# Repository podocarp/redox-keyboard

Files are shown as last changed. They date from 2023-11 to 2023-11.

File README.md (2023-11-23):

## Changes

This is a fork of the original. Additions:
- Added v1 version that uses low profile Kailh choc hot swap sockets compatible
  with both v1 and v2 switches
- Added v1 version that uses Kailh MX hot swap sockets

<p align="center">
Redox logo
QMK
</p>

<h3 align="center">The Redox project repository</h3>

<div align="center">

[]()




</div>

---

The Redox project is an open-source, [QMK (Quantum Mechanical Keyboard Firmware)](https://github.com/qmk/qmk_firmware) powered, ergonomic split mechanical keyboard. This repository will be used to share information about the project and instruction on how to use and assemble the Redox keyboard.

<p align="center">
Redox
</p>

**Designer's bio**: [Mattia Dal Ben (aka u/TiaMaT102)](mailto:matthewdibi@gmail.com) obtained a master's degree in Electrical Engineering with a specialization in Computer Science at the University of Udine. Currently works as a Software Engineer in R&D department for a big IoT and Embedded Computers company. Mechanical keyboard enthusiast and maker, the Redox keyboard is the result of all of his passions.

## Rationale

The Redox is a keyboard project designed with ergonomics in mind. It uses Cherry MX style mechanical switches laid out in a 7x5 columnar stagger layout with components that can easily be sourced.

The design was heavily inspired by the [Ergodox keyboard](https://www.ergodox.io/), and its main goal is to reduce the size without sacrificing too many keys, hence the name **Re**duced Ergo**dox**.

As an Ergodox user I couldn't ignore the few flaws of the original design and in a moment of arrogance I tried to fix them, thus the Redox features:
- Easier to reach thumb cluster.
- Additional easy-to-reach rotated 1.25u thumb key.
- Reduced size.
- Reduced costs (the Redox uses Arduino Pro Micro instead of the Teensy 2.0).
- Either half can be plugged in to the PC since each half can act as the master.
- Either half can work as a standalone keyboard to be used as a macropad/gaming keyboard.
- RGB backlighting support.
- 3D-printer friendly case.
- Wireless [see section below](#wireless-implementations)
- [VIA](https://caniusevia.com/) compatible (thanks to [Harshit Goel](https://github.com/harshitgoel96))
- [ZMK firmware](https://zmk.dev/) compatible (thanks to [toddmok](https://github.com/toddmok))
- [KMK firmware](http://kmkfw.io/) compatible

## Related Projects

- [**Redox handwire**](https://www.thingiverse.com/thing:2704567): The first incarnation of the Redox keyboard. It consists of a 3D-printed case and a handwired matrix.
  - [Tilted Redox case](https://www.thingiverse.com/thing:2767216): tilted case for the Redox prototype by jschloer.
    - [Tilted redox case pro micro](https://www.printables.com/model/382413-tilted-redox-case-for-micro-and-usbc): Remix of the tilted case to support pro micro and usb c instead of TRRS. 

  - [couscous-kbd](https://gitlab.com/cschalkwijk/couscous-kbd): Redox-inspired parametric OpenSCAD keyboard design.
  - [Redox tenting kit](https://www.thingiverse.com/make:484843): modified base to support tenting, mini-USB for the interconnect, and a hole for microswitch for reset needed when uploading new firmware by [Lenbok](https://github.com/Lenbok).
  - [Iris-inspired Redox case](https://github.com/Lenbok/scad-redox-case): a case inspired both by the Redox rev1.0 and the Iris designed with OpenSCAD by [Lenbok](https://github.com/Lenbok).
  - [Redodactyl keyboard](https://www.reddit.com/r/MechanicalKeyboards/comments/9j5pw5/enter_the_redodactyl_first_build/): handwired 3D printed Dactyl-inspired Redox variant by u/darknao.
- [**Redox Manuform**](https://www.thingiverse.com/thing:3503380): full rework of the Redox case inspired by the Dactyl Manuform. Designed by [Fosk\_LL](https://www.thingiverse.com/Fosk_LL/about).
- [**Redox rev1.0**](https://github.com/mattdibi/redox-keyboard/tree/master/redox): the Redox rev 1.0 is the first commercially available version of the Redox keyboard.
	- Rev1.0 PCBs: available at [Falbatech's store](https://falba.tech/product/redox-pcb-electrical-boards-set-of-2/)
    - Firmware sources:
        - [QMK firmware for Redox](https://github.com/mattdibi/qmk_firmware/tree/master/keyboards/redox)
        - [KMK firmware for Redox](https://github.com/KMKfw/kmk_firmware/tree/master/boards/redox)
	- 3D-printable cases:
        - [3D printable case](https://www.thingiverse.com/thing:2886662), freely available.
        - [Redox keyboard case (high profile)](https://www.thingiverse.com/thing:3825752), by [Michele Ferri](https://www.thingiverse.com/sako83/about).
        - [Travel-friendly Redox Keyboard case](https://www.thingiverse.com/thing:3607303), by [Fosk\_LL](https://www.thingiverse.com/Fosk_LL/about).
        - [Redox Neodox case](https://github.com/Pastitas/Redox-neodox-Case), by [Pastitas](https://github.com/Pastitas)
        - [Redox big battery](https://github.com/marco-silvestri/redox-big-battery), by [Marco Silvestri](https://github.com/marco-silvestri).
	- Commercially available cases:
		- [Falbatech's bamboo cases with tilt kit](https://falba.tech/product/redox-standard-lift-bamboo-wood-case-with-oil-finish/)
		- [Falbatech's fullhand bamboo cases](https://falba.tech/product/redox-fullhand-bamboo-wood-case-with-oil-finish-ver-2/)
- [**Redox rev1.0W**](https://github.com/mattdibi/redox-keyboard/tree/master/redox-w): the Redox rev 1.0W is the wireless version of the Redox keyboard.
    - Rev1.0W PCBs: gerbers available in [this repo](https://github.com/mattdibi/redox-keyboard/tree/master/redox-w/rev1.0W).
    - Falbatech's Rev1.0W Hot-swap PCBs: available at [Falbatech's store](https://falba.tech/product/redox-wireless-pcb-electrical-boards-set-of-2/) (Incompatible with the 3D-printable cases down below)
    - Firmware sources:
        - [QMK firmware for Redox wireless](https://github.com/mattdibi/qmk_firmware/tree/master/keyboards/redox_w)
        - [Nordic MCUs firmware for Redox wireless](https://github.com/mattdibi/redox-w-firmware)
	- 3D-printable cases:
        - [3D printed case](https://github.com/mattdibi/redox-keyboard/tree/master/redox-w/case), freely available.
        - [Redox Neodox case](https://github.com/Pastitas/Redox-neodox-Case), by [Pastitas](https://github.com/Pastitas)
    - Commercially available cases (only compatible with the Falbatech's store PCBs):
        - [Falbatech's bamboo and aliminium cases](https://falba.tech/product/redox-wireless-standard-lift-bamboo-wood-case-with-oil-finish/)
		- [Falbatech's fullhand bamboo cases](https://falba.tech/product/redox-wireless-standard-lift-bamboo-wood-case-with-oil-finish-ver-1/)
- [**Redox rev2.0WHS**](https://github.com/mattdibi/redox-keyboard/tree/master/redox-w): the Redox rev 2.0WHS is the wireless hot-swappable version of the Redox keyboard.
    - Rev2.0WHS PCBs: gerber files available [here](https://github.com/mattdibi/redox-keyboard/tree/master/redox-w/rev2.0WHS/pcb)
    - Firmware sources:
        - [QMK firmware for Redox wireless](https://github.com/mattdibi/qmk_firmware/tree/master/keyboards/redox_w)
        - [Nordic MCUs firmware for Redox wireless](https://github.com/mattdibi/redox-w-firmware)
	- 3D-printable case:
        - [3D printed case](https://github.com/mattdibi/redox-keyboard/tree/master/redox-w/rev2.0WHS/case), freely available.

## Wireless Implementations

The Redox keyboard uses three different wireless implementations, differentiated by firmware:
 - *QMK based*: Leveraging the [Gazel protocol](https://developer.nordicsemi.com/nRF5_SDK/nRF51_SDK_v5.x.x/doc/5.2.0/html/a00140.html). It needs its own PCB and a receiver dongle (see [Redox Wireless](https://github.com/mattdibi/redox-keyboard/tree/docs/zmk_update/redox-w) for details) and needs three YJ-14015 MCUs + a Pro Micro compatible controller.
 - *ZMK based*: Leveraging the Bluetooth protocol. It is based on the [Redox wired PCB](https://github.com/mattdibi/redox-keyboard/tree/master/redox) and the [nice!nano](https://nicekeyboards.com/nice-nano/) controller.
 - *KMK based*: Adding [Bluetooth Split](http://kmkfw.io/docs/split_keyboards#bluetooth-split-aka-no-trrs-currently-in-testing) code to `boards/redox/main.py`. Combined with a [compatible](http://kmkfw.io/docs/Officially_Supported_Microcontrollers) wireless controller completes wireless configuration. Would advice adding [Bluetooth keycodes](http://kmkfw.io/docs/keycodes#bluetooth-keys) in keymap; `keyboard.keymap` element in `main.py`.

 The notable differences for the three implementations are as follows:
 - _Battery life_: QMK Redox Wireless uses two CR2032 coin cell batteries which last [approximately one year (YMMV)](https://github.com/mattdibi/redox-keyboard/tree/master/redox-w#battery-usage), while the nice!nano support LiPo rechargable batteries (you can choose the capacity you want but expect them to last for a [few weeks on a single charge](https://zmk.dev/power-profiler)).
 - _Flexibility_: The receiver dongle limits the flexibility of QMK Redox Wireless.
 - _Cost_: The 3x YJ-14015 + Pro Micro combo is cheaper than two wireless controllers required for ZMK and wireless KMK.
 - _Range_: Bluetooth implementations, of ZMK and KMK, should be more capable than what can be achieved with the QMK Redox Wireless (At this point in time, I lack the evidence to support these claims though).

## Physical Key Layout

<p align="center">
Redox layout
</p>

### Keycaps

| Size  | Qty | Notes |
|---|:---:|:---:|
| 1.5u  | 6 | |
| 1.25u |  10 | You can get away with 8 if you use two 1u keycaps for the 1.25u rotated keys |
| 1u |  54 | |

> :information_source: On [pimpmykeyboard.com](https://pimpmykeyboard.com/sa-1976-keyset-two-shot/) site you can find a SA 1976 keyset kit specifically made for the Redox keyboard: the "Ergo Redox kit (12 keys)".

## Affiliations

In partnership with Falbatech you can now use the code "**mattdibi05**" on Falbatech's store for a 5% OFF special discount.

## Donations

If you've read this far and found something useful, please consider donating to help me maintain and further develop this project.

<p align="center">
<a href="https://www.paypal.me/MattiaDalBen">Donate button</a>
</p>

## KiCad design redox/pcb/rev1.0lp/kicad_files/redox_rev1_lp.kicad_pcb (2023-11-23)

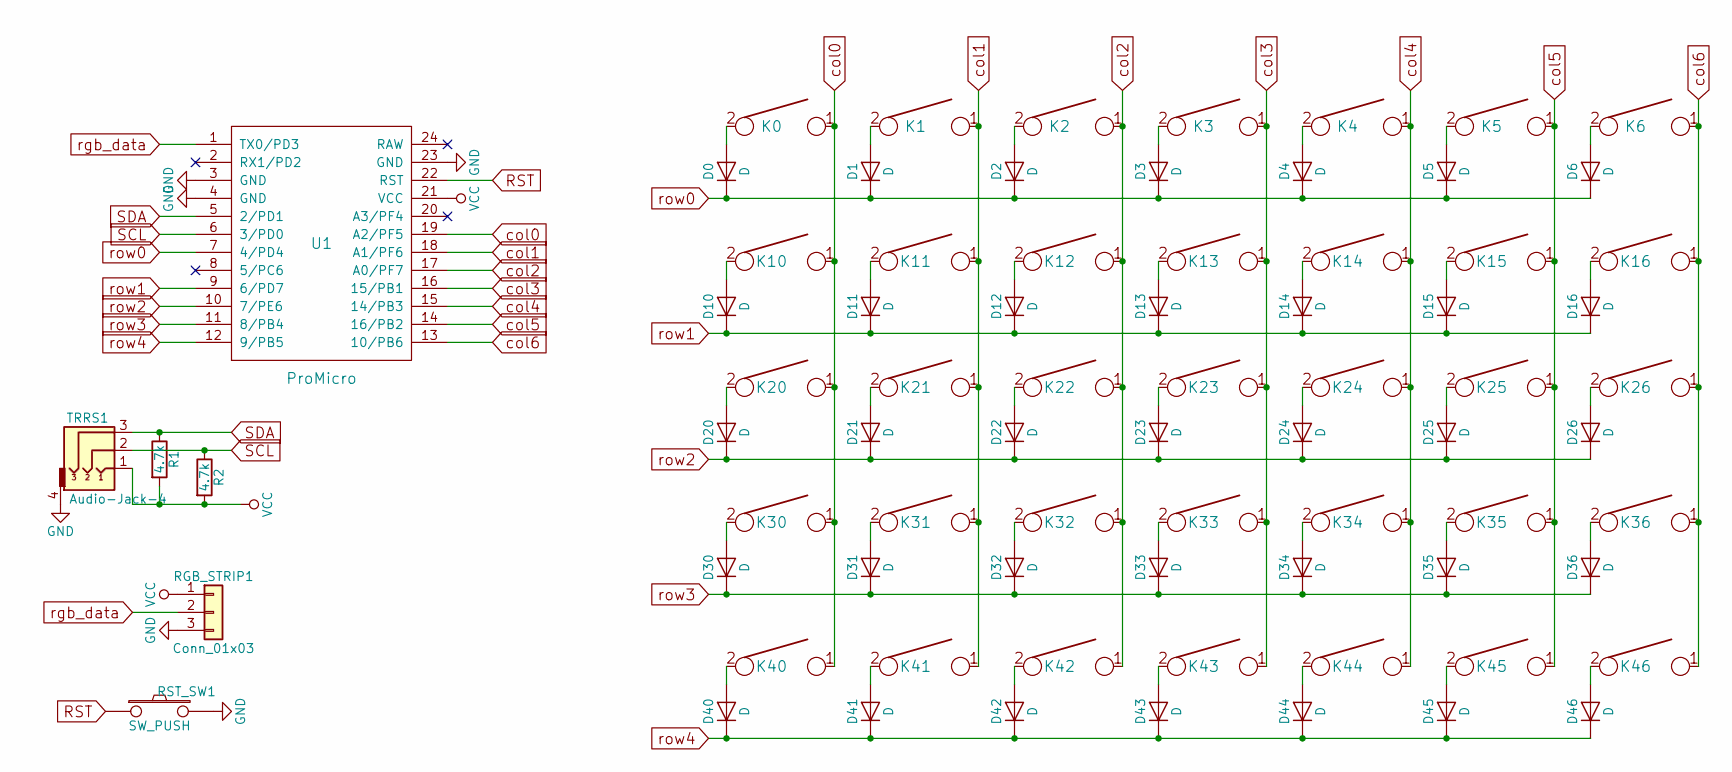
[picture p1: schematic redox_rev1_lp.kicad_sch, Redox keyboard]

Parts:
D0, D1, D2, D3, D4, D5, D6, D10, D11, D12, D13, D14, D15, D16, D20, D21, D22, D23, D24, D25, D26, D30, D31, D32, D33, D34, D35, D36, D40, D41, D42, D43, D44, D45, D46: D; Diode-dual
K0, K10, K20, K30, K44: KEYSW; SW_Hotswap_Kailh_Choc_V1V2_1.25u
K1, K2, K3, K4, K5, K6, K11, K12, K13, K14, K15, K21, K22, K23, K24, K25, K26, K31, K32, K33, K34, K35, K36, K40, K41, K42, K43: KEYSW; SW_Hotswap_Kailh_Choc_V1V2_1.00u
K16, K45, K46: KEYSW; SW_Hotswap_Kailh_Choc_V1V2_1.50u
R1, R2: 4.7k; Resistor-Compact
RGB_STRIP1: Conn_01x03; Pin_Header_Straight_1x03_Pitch2.54mm
RST_SW1: SW_PUSH; SW_PUSH_6mm_h4.3mm
TRRS1: Audio-Jack-4; TRRS-PJ-320A-dual
U1: ProMicro; ArduinoProMicro

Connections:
GND: RGB_STRIP1.3, RST_SW1.2, TRRS1.4, U1.3 (GND), U1.4 (GND), U1.23 (GND)
unnamed: D0.2 (A), K0.2
unnamed: D1.2 (A), K1.2
unnamed: D2.2 (A), K2.2
unnamed: D3.2 (A), K3.2
unnamed: D4.2 (A), K4.2
unnamed: D5.2 (A), K5.2
unnamed: D6.2 (A), K6.2
unnamed: D10.2 (A), K10.2
unnamed: D11.2 (A), K11.2
unnamed: D12.2 (A), K12.2
unnamed: D13.2 (A), K13.2
unnamed: D14.2 (A), K14.2
unnamed: D15.2 (A), K15.2
unnamed: D16.2 (A), K16.2
unnamed: D20.2 (A), K20.2
unnamed: D21.2 (A), K21.2
unnamed: D22.2 (A), K22.2
unnamed: D23.2 (A), K23.2
unnamed: D24.2 (A), K24.2
unnamed: D25.2 (A), K25.2
unnamed: D26.2 (A), K26.2
unnamed: D30.2 (A), K30.2
unnamed: D31.2 (A), K31.2
unnamed: D32.2 (A), K32.2
unnamed: D33.2 (A), K33.2
unnamed: D34.2 (A), K34.2
unnamed: D35.2 (A), K35.2
unnamed: D36.2 (A), K36.2
unnamed: D40.2 (A), K40.2
unnamed: D41.2 (A), K41.2
unnamed: D42.2 (A), K42.2
unnamed: D43.2 (A), K43.2
unnamed: D44.2 (A), K44.2
unnamed: D45.2 (A), K45.2
unnamed: D46.2 (A), K46.2
RST: RST_SW1.1, U1.22 (RST)
SCL: R2.1, TRRS1.2, U1.6 (3/PD0)
SDA: R1.1, TRRS1.3, U1.5 (2/PD1)
VCC: R1.2, R2.2, RGB_STRIP1.1, TRRS1.1, U1.21 (VCC)
col0: K0.1, K10.1, K20.1, K30.1, K40.1, U1.19 (A2/PF5)
col1: K1.1, K11.1, K21.1, K31.1, K41.1, U1.18 (A1/PF6)
col2: K2.1, K12.1, K22.1, K32.1, K42.1, U1.17 (A0/PF7)
col3: K3.1, K13.1, K23.1, K33.1, K43.1, U1.16 (15/PB1)
col4: K4.1, K14.1, K24.1, K34.1, K44.1, U1.15 (14/PB3)
col5: K5.1, K15.1, K25.1, K35.1, K45.1, U1.14 (16/PB2)
col6: K6.1, K16.1, K26.1, K36.1, K46.1, U1.13 (10/PB6)
rgb_data: RGB_STRIP1.2, U1.1 (TX0/PD3)
row0: D0.1 (K), D1.1 (K), D2.1 (K), D3.1 (K), D4.1 (K), D5.1 (K), D6.1 (K), U1.7 (4/PD4)
row1: D10.1 (K), D11.1 (K), D12.1 (K), D13.1 (K), D14.1 (K), D15.1 (K), D16.1 (K), U1.9 (6/PD7)
row2: D20.1 (K), D21.1 (K), D22.1 (K), D23.1 (K), D24.1 (K), D25.1 (K), D26.1 (K), U1.10 (7/PE6)
row3: D30.1 (K), D31.1 (K), D32.1 (K), D33.1 (K), D34.1 (K), D35.1 (K), D36.1 (K), U1.11 (8/PB4)
row4: D40.1 (K), D41.1 (K), D42.1 (K), D43.1 (K), D44.1 (K), D45.1 (K), D46.1 (K), U1.12 (9/PB5)

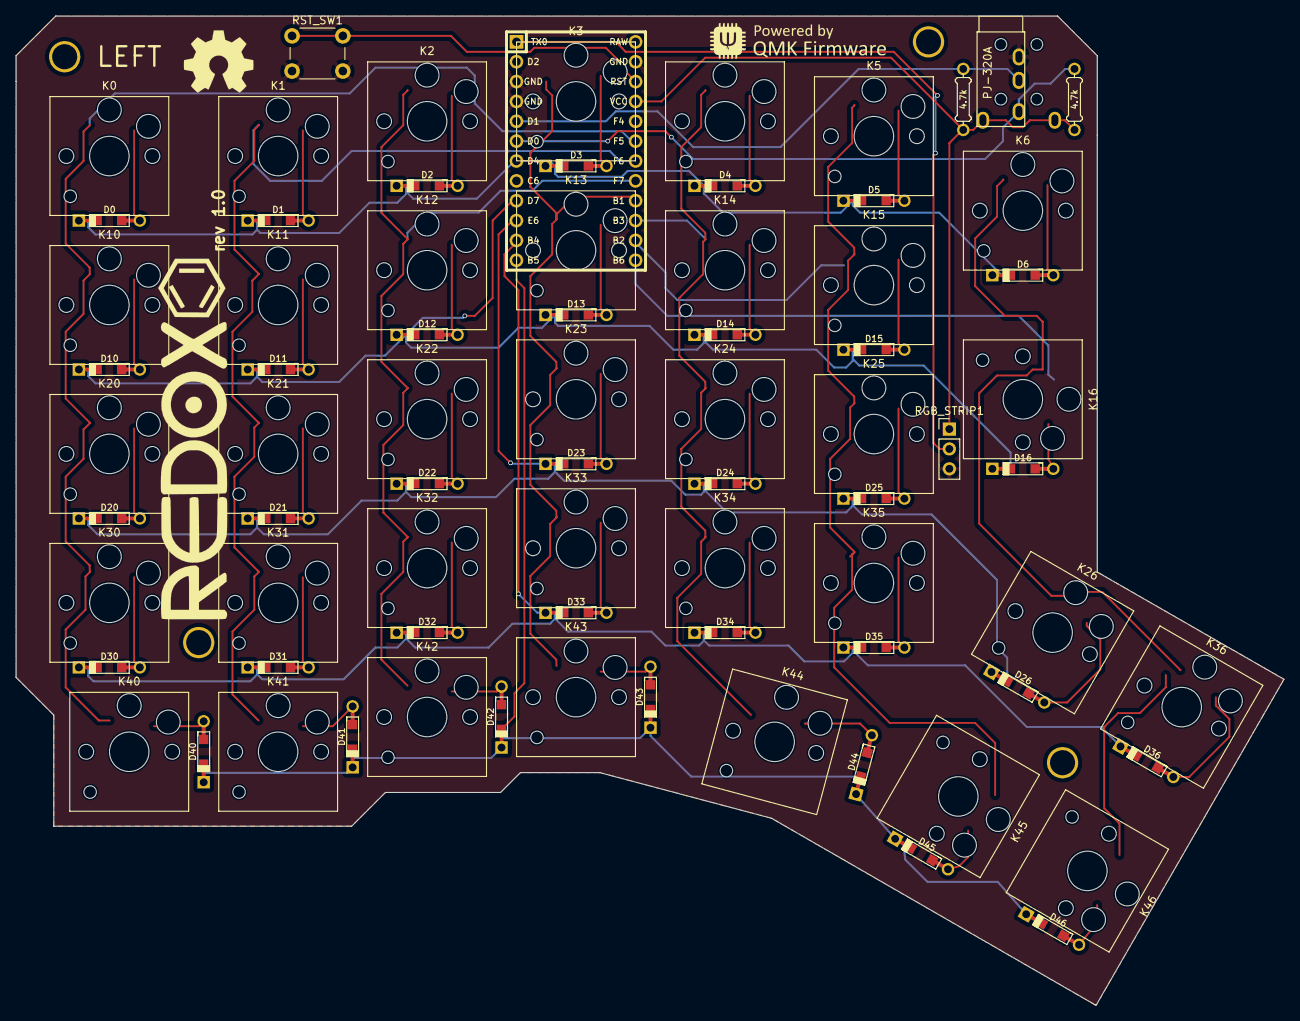
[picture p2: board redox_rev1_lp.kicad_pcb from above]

Board: 2 copper layers, 162.2 x 126.5 mm, 80 parts (0 on the bottom side), 53 nets.

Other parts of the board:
HOLE_M3, HOLE_M3#2, HOLE_M3#3, HOLE_M3#4: VAL**; HOLE_M3

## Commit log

2023-11-21 change to kailh choc hotswap sockets
    [redox_rev1.kicad_pcb, redox_rev1.kicad_sch]
2023-11-23 move lp to new folder, restore old one
    [redox_rev1.kicad_pcb, redox_rev1.kicad_sch, redox_rev1.sch]
2023-11-23 move switch footprints into local folder and change schematic to use them instead
    [redox_rev1.kicad_pcb, redox_rev1.kicad_sch]

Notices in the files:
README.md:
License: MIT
